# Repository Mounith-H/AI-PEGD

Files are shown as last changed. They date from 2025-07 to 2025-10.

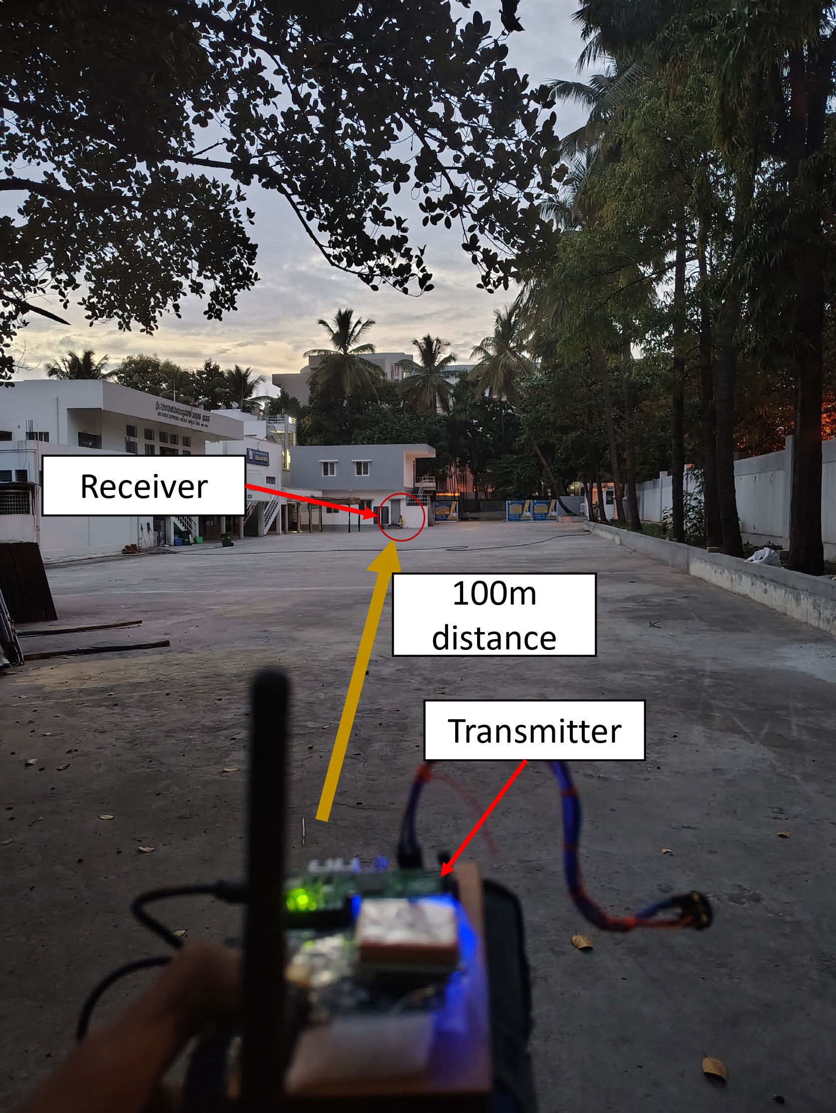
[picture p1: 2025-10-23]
images/field_test.jpg

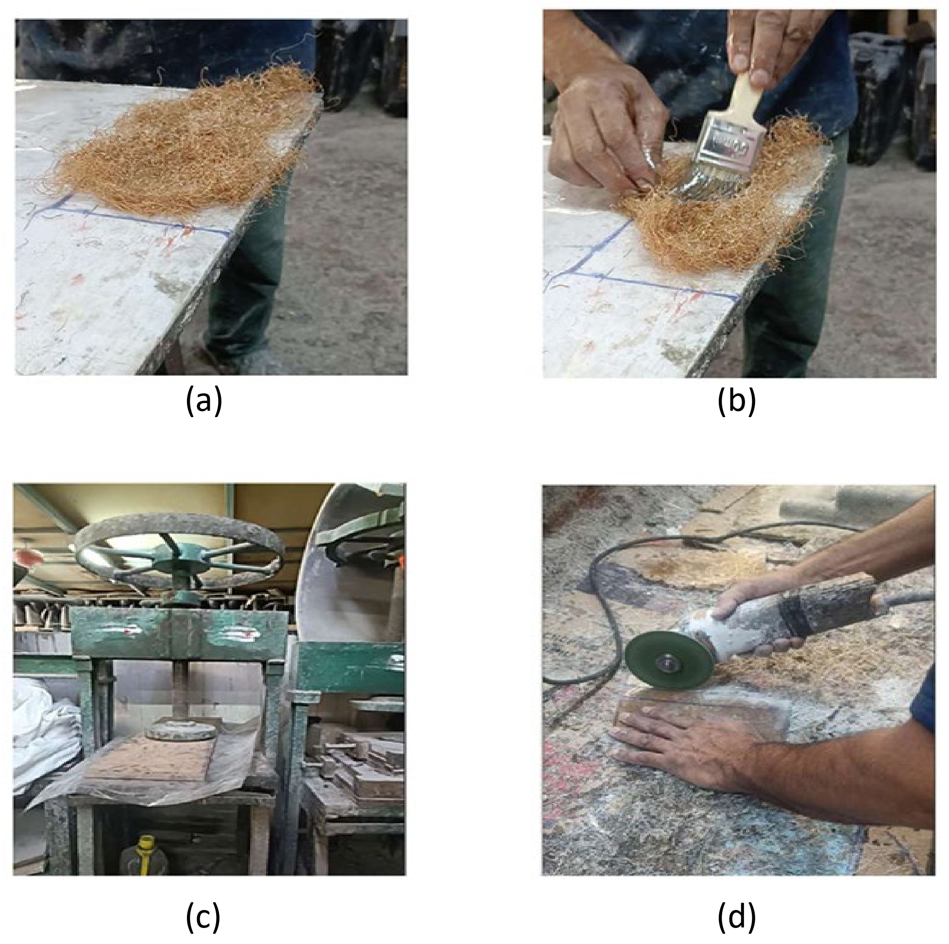
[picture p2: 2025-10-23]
images/enclosore_design.jpg

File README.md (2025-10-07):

# AI Powered Edge Based Gunshot Detection for Protecting Wildlife

## Project Overview
This project implements an intelligent gunshot detection system using Raspberry Pi Pico for wildlife protection. The system uses machine learning to detect gunshot sounds and reports their location in real-time, helping authorities respond quickly to potential poaching incidents.

## Current Implementation Status

### Completed Features
1. **Hardware Integration**
   - INMP441 Digital Microphone setup with I2S interface
   - GPS Module (NEO-6M) integration with UART
   - NRF24L01 Radio Module for wireless communication
   - Power Management using IP5306 with PIO-based PWM control:
     - Continuous KEY pin pulsing using PIO state machine
     - 16-bit resolution PWM implementation
     - Automatic power maintenance during operation

2. **Core Functionality**
   - Real-time audio sampling using PIO and DMA
   - GPS location tracking with NMEA parsing
   - Wireless data transmission with packet fragmentation
   - Power management with robust PIO implementation:
     - Efficient KEY pin control
     - Reliable power maintenance
     - Clean initialization sequence

3. **System Architecture**
   - Dual-core operation:
     - Core 0: System management, GPS, and radio communication
     - Core 1: Audio processing and gunshot detection
   - PIO-based peripheral management:
     - Audio sampling
     - Power control
     - Communication protocols

4. **Reliability Features**
   - Robust power management with PWM-based IP5306 control:
     - Continuous operation guarantee
     - Power stability monitoring
     - Automatic recovery on power events
   - Error handling and recovery mechanisms
   - Packet fragmentation for reliable data transmission
   - Automatic retry mechanisms for radio communication

### Work in Progress
1. **Machine Learning Integration**
   - TensorFlow Lite model integration
   - Model optimization for Pico
   - Real-time inference implementation

2. **Communication Protocol**
   - Mesh network implementation
   - Data encryption
   - Acknowledgment system

### Future Work
1. **System Features**
   - Web interface for monitoring
   - Mobile app development
   - Multiple node coordination
   - Over-the-air updates

2. **ML Improvements**
   - Model retraining with field data
   - False positive reduction
   - Sound classification expansion

3. **Hardware Improvements**
   - Weather-proof enclosure design
   - Solar charging integration
   - Extended range communication

## Hardware Setup
### Components
- Raspberry Pi Pico
- INMP441 Digital Microphone
- NEO-6M GPS Module
- NRF24L01 Radio Module
- IP5306 Power Management IC

- **Power Control**:
  - Power control implemented through PIO state machine
  - Continuous PWM signal maintains power module operation

## Building and Running
### Prerequisites
1. Install CMake (version 3.12 or higher)
2. Install Raspberry Pi Pico SDK
3. Set PICO_SDK_PATH environment variable

### Build Instructions
1. Create build directory:
   ```bash
   mkdir build
   cd build
   ```

2. Generate build files:
   ```bash
   cmake ..
   ```

3. Build the project:
   ```bash
   make
   ```

4. Flash the binary:
   - Hold BOOTSEL button while connecting Pico
   - Copy generated .uf2 file to mounted drive

### Power Management Notes
- The system uses PIO-based power control for the IP5306
- KEY pin requires continuous pulsing to maintain power
- PWM implementation ensures reliable operation
- No manual intervention needed after initial power-up

## Contributing
Contributions are welcome! Please read the contributing guidelines before submitting pull requests.

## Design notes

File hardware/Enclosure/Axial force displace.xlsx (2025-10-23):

MTS793|BTW|ENU|1|0|.|/|:|1|0|0|A
Data Header: Time: 2048.0078 s 5/13/2025 4:09:34 PM
Data Acquisition: Timed
Station Name: 10629574 w ext.cfg
Test File Name: Untitled test
Axial Force Axial Displacement Time
kN | mm | s
2.1577883 | 0.53644472 | 1.0058594
2.1624367 | 0.54335147 | 2.0058594
2.1644783 | 0.54634267 | 3.0058594
2.1647153 | 0.54781216 | 4.0058594
2.1628492 | 0.54907978 | 5.0058594
2.1625283 | 0.54998457 | 6.0058594
2.1607583 | 0.55126494 | 7.0058594
2.1571965 | 0.55169493 | 8.0058594
2.1579719 | 0.55303329 | 9.0058594
2.1613309 | 0.55302805 | 10.005859
2.1653202 | 0.55400676 | 11.005859
2.1636591 | 0.55546653 | 12.005859
2.1633389 | 0.55449086 | 13.005859
2.1691735 | 0.5558036 | 14.005859
2.1675892 | 0.55581975 | 15.005859
2.1672471 | 0.55782229 | 16.005859
2.1608047 | 0.55742198 | 17.005859
2.1654606 | 0.55737203 | 18.005859
2.1592593 | 0.55784929 | 19.005859
2.1604385 | 0.55761653 | 20.005859
2.1584291 | 0.55777705 | 21.005859
2.1655483 | 0.55822724 | 22.005859
2.1641695 | 0.55928248 | 23.005859
2.1653185 | 0.55874401 | 24.005859
2.16677 | 0.5593316 | 25.005859
2.167227 | 0.55964351 | 26.005859
2.1643686 | 0.56017697 | 27.005859
2.1658328 | 0.55947161 | 28.005859
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

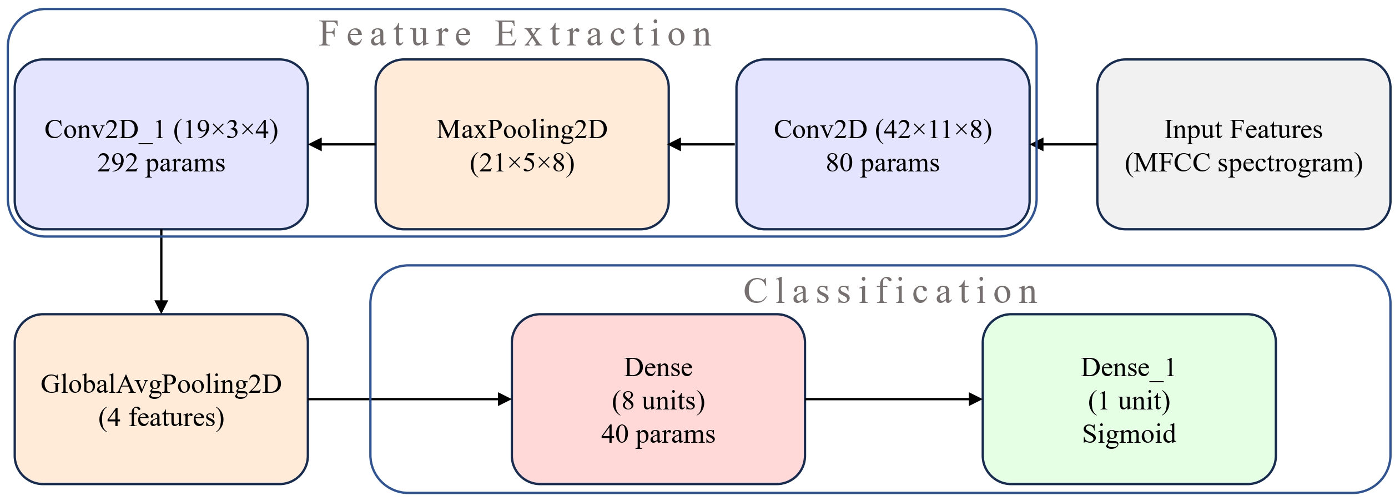
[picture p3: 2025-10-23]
images/CNN_architecture.jpg

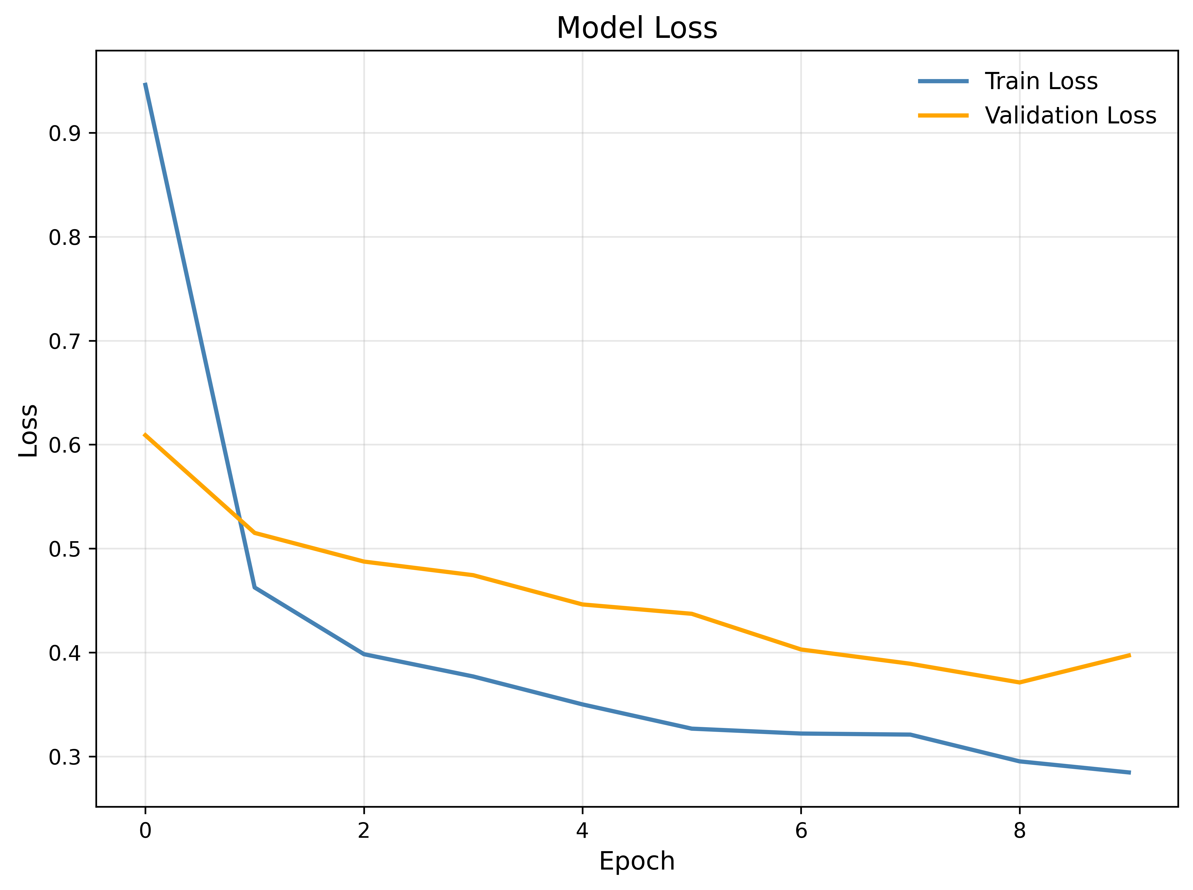
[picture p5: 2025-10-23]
images/loss_plot_400.png

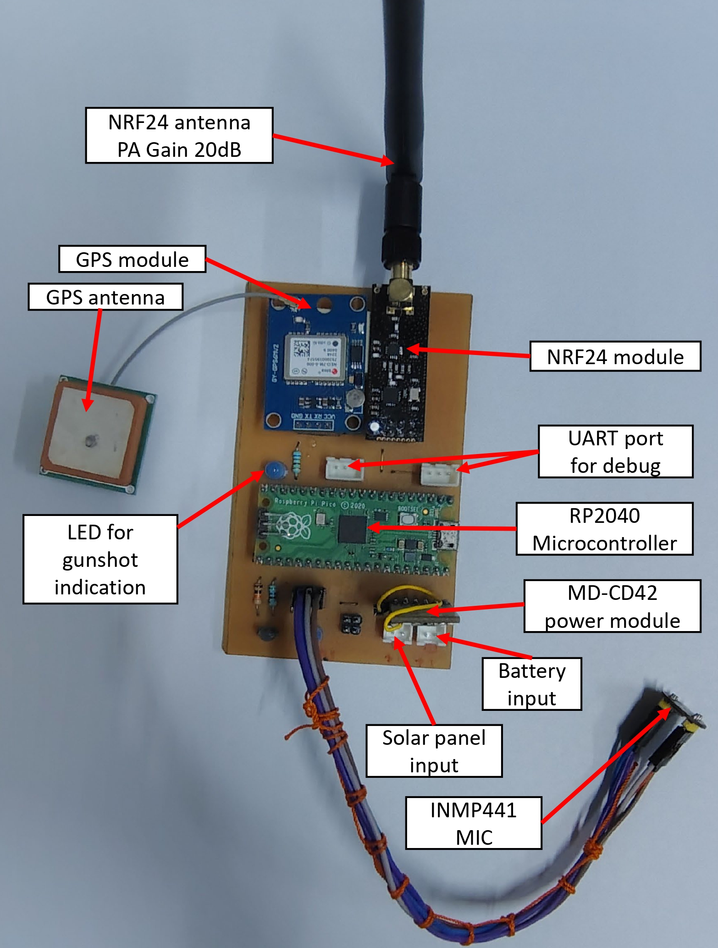
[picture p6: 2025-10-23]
images/transmitter_node.jpg

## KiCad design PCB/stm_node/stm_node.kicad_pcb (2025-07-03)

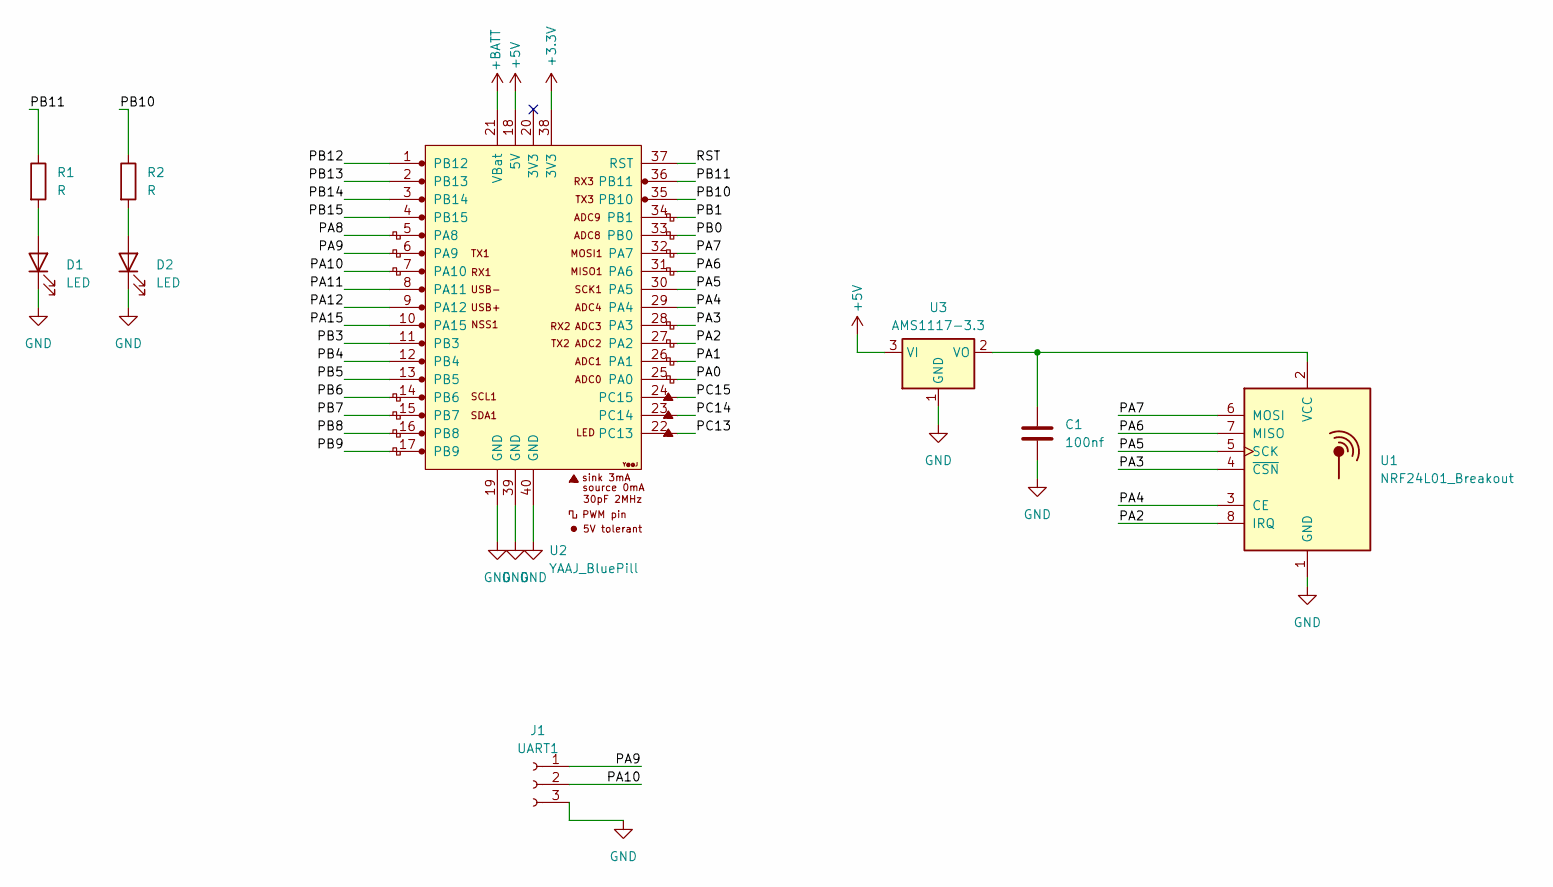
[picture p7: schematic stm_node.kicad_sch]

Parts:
C1: 100nf; CP_EIA-3528-12_Kemet-T_HandSolder
D1, D2: LED; LED_D5.0mm
J1: UART1; JST_XH_B3B-XH-A_1x03_P2.50mm_Vertical
R1, R2: R; R_Axial_DIN0207_L6.3mm_D2.5mm_P10.16mm_Horizontal
U1: NRF24L01_Breakout; nRF24L01_Breakout
U2: YAAJ_BluePill; YAAJ_BluePill_1
U3: AMS1117-3.3; SOT-223-3_TabPin2

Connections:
+3.3V: U2.38 (3V3)
+5V: U2.18 (5V), U3.3 (VI)
+BATT: U2.21 (VBat)
/PA0: U2.25 (PA0)
/PA1: U2.26 (PA1)
/PA2: U1.8 (IRQ), U2.27 (PA2)
/PA3: U1.4 (~CSN), U2.28 (PA3)
/PA4: U1.3 (CE), U2.29 (PA4)
/PA5: U1.5 (SCK), U2.30 (PA5)
/PA6: U1.7 (MISO), U2.31 (PA6)
/PA7: U1.6 (MOSI), U2.32 (PA7)
/PA8: U2.5 (PA8)
/PA9: J1.1, U2.6 (PA9)
/PA10: J1.2, U2.7 (PA10)
/PA11: U2.8 (PA11)
/PA12: U2.9 (PA12)
/PA15: U2.10 (PA15)
/PB0: U2.33 (PB0)
/PB1: U2.34 (PB1)
/PB3: U2.11 (PB3)
/PB4: U2.12 (PB4)
/PB5: U2.13 (PB5)
/PB6: U2.14 (PB6)
/PB7: U2.15 (PB7)
/PB8: U2.16 (PB8)
/PB9: U2.17 (PB9)
/PB10: R2.1, U2.35 (PB10)
/PB11: R1.1, U2.36 (PB11)
/PB12: U2.1 (PB12)
/PB13: U2.2 (PB13)
/PB14: U2.3 (PB14)
/PB15: U2.4 (PB15)
/PC13: U2.22 (PC13)
/PC14: U2.23 (PC14)
/PC15: U2.24 (PC15)
/RST: U2.37 (RST)
GND: C1.2, D1.1 (K), D2.1 (K), J1.3, U1.1 (GND), U2.19 (GND), U2.39 (GND), U2.40 (GND), U3.1 (GND)
unnamed: D1.2 (A), R1.2
unnamed: D2.2 (A), R2.2
unnamed: C1.1, U1.2 (VCC), U3.2 (VO)

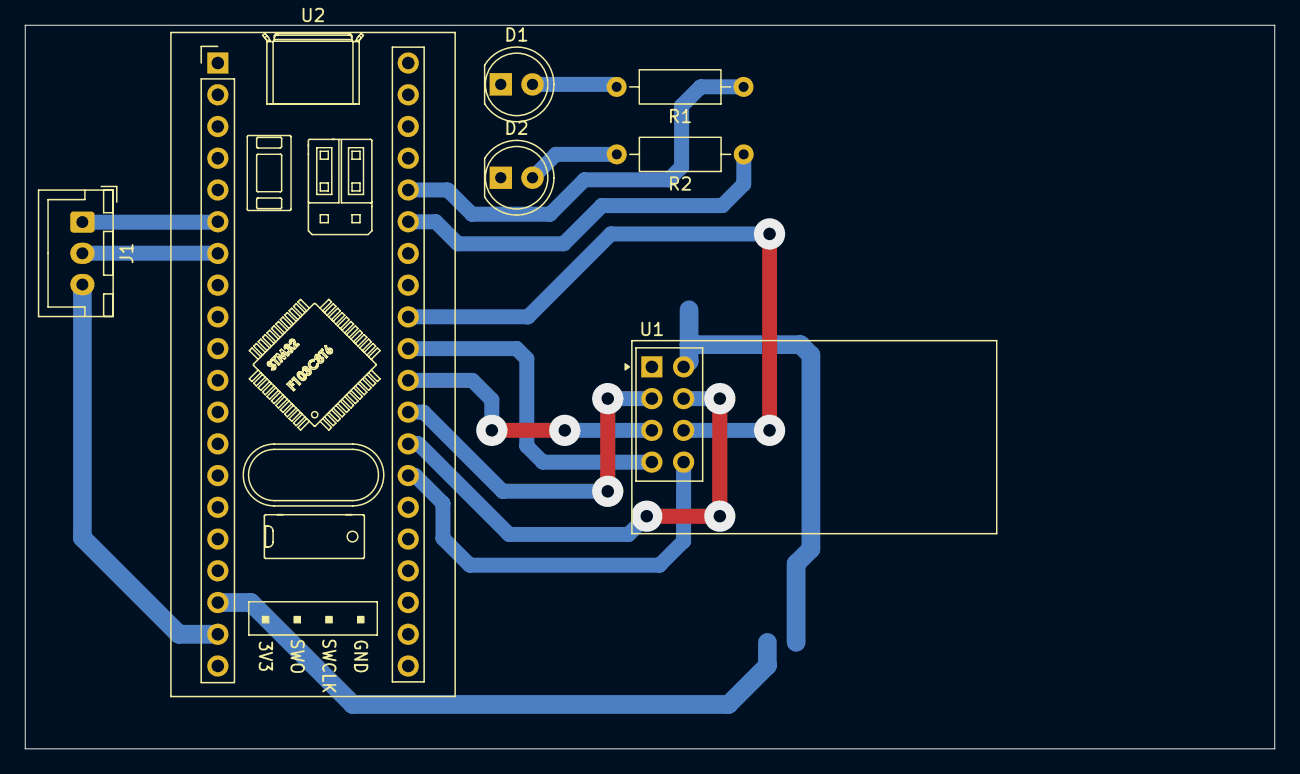
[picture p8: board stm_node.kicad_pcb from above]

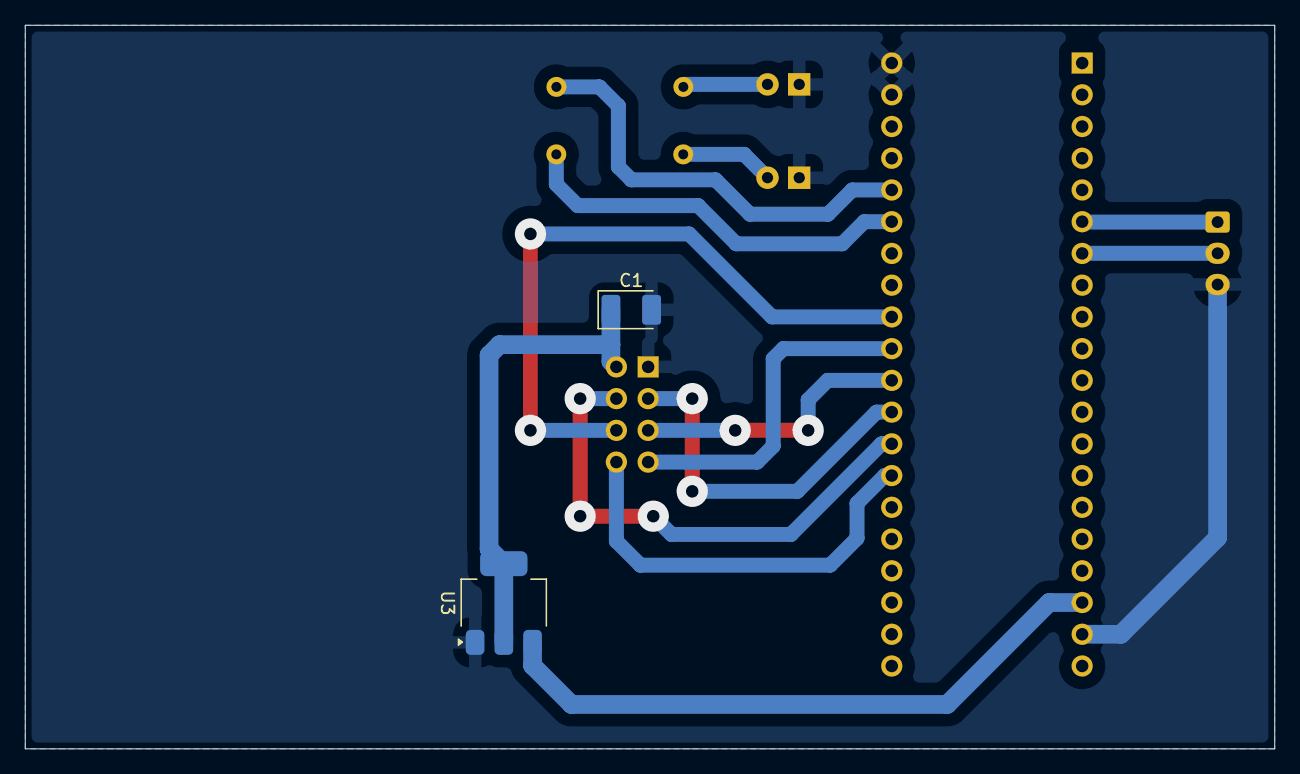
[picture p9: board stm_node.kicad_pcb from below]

Board: 2 copper layers, 100.0 x 57.9 mm, 9 parts (2 on the bottom side), 15 nets.

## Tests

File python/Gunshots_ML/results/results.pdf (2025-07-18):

# Gunshot Detection for Wildlife Protection: Machine Learning Model Results and RP2040 Deployment

### ML-Based Gunshot Detection System

### July 3, 2025

Abstract

This document presents comprehensive results from a machine learning-based gunshot detection system designed for wildlife protection. The system utilizes TensorFlow with enhanced feature extraction from audio signals and has been optimized for deployment on RP2040 microcontrollers. The model achieves 97.8% accuracy with significant size reduction through quantization for edge computing applications.

## 1 Introduction

Wildlife protection requires real-time monitoring systems capable of detecting illegal hunting activities, particularly gunshots. This project implements a machine learning solution using TensorFlow that processes audio signals to distinguish between gunshots and environmental sounds. The system has been optimized for deployment on resource-constrained RP2040 microcontrollers using TensorFlow Lite with INT8 quantization.

## 2 Dataset and Methodology

### 2.1 Dataset Composition

The training dataset consists of:

Environment Sounds: 2,000 audio samples

Gunshot Sounds: 851 audio samples

Audio Format: 2-second clips at 22.05 kHz sampling rate

Total Samples: 2,851 audio files

### 2.2 Data Balancing

To address class imbalance, the following strategy was employed:

Environment sounds: Reduced to 1,702 samples (stratified sampling)

Gunshot sounds: Oversampled to 1,702 samples

Final balanced dataset: 3,404 samples (1,702 each class)

### 2.3 Feature Extraction

The system extracts 3,045 features from each audio clip:

Table 1: Audio Feature Extraction Summary

Feature Type | Dimensions | Count
MFCC Coefficients | 20 Ö 87 frames | 1,740
Spectral Centroid | 87 frames | 87
Spectral Rolloff | 87 frames | 87
Zero Crossing Rate | 87 frames | 87
Chroma Features | 12 Ö 87 frames | 1,044
Total Features | 3,045

## 3 Model Architecture

### 3.1 Neural Network Design

The enhanced TensorFlow model consists of:

Table 2: Neural Network Architecture

Layer | Neurons Activation Dropout
Input + Dense | 256 | ReLU | 30%
BatchNorm + Dense | 128 | ReLU | 40%
BatchNorm + Dense | 64 | ReLU | 30%
BatchNorm + Dense | 32 | ReLU | 20%
Output | 1 | Sigmoid | -

### 3.2 Training Configuration

Optimizer: Adam (lr=0.001, =0.9, =0.999)

Loss Function: Binary Crossentropy

Batch Size: 16

Maximum Epochs: 100

Early Stopping: Patience = 15 epochs

Validation Split: 20%

## 4 Model Performance Results

### 4.1 Primary Metrics

The enhanced model achieved the following performance on the test set:

Table 3: Model Performance Metrics

| Metric | Score

Test Accuracy 97.80%
Test Precision | 97.94%
| Test Recall | 97.65%
| F1 Score | 97.79%

### 4.2 Confusion Matrix

The confusion matrix on the test set (681 samples):

Table 4: Confusion Matrix Results

Predicted Environment Predicted Gunshot

Actual Environment | | 334 | | 7
Actual Gunshot | 8 | 332

### 4.3 Classification Report

Detailed per-class performance:

Table 5: Per-Class Performance Metrics

Class | Precision Recall F1-Score Support
Environment | 0.98 | 0.98 | 0.98 | 341
Gunshot | 0.98 | 0.98 | 0.98 | 340
Accuracy | | | 0.98 | 681
Macro Avg | 0.98 | 0.98 | 0.98 | 681
Weighted Avg | 0.98 | 0.98 | 0.98 | 681

## 5 RP2040 Optimization Results

### 5.1 Model Quantization

For deployment on RP2040 microcontrollers, the model underwent INT8 quantization:

Table 6: Model Size Optimization

Model Format | Size | Reduction
Original (.h5) | 9.51 MB | -
TensorFlow Lite (.tflite) 0.80 MB | 91.6%
C Header (.h) | 5.0 MB | -

### 5.2 Quantized Model Performance

The quantized TensorFlow Lite model maintains high accuracy:

Table 7: Quantized Model Test Results

Metric | Value
Input Type | INT8
Output Type | INT8
Input Shape | [1, 3045]
Output Shape | [1, 1]
Test Confidence | 99.61%
Model Size | 820.02 KB

## 6 Deployment Specifications

### 6.1 RP2040 Memory Requirements

Flash Memory: 820 KB for model storage

RAM: 100 KB for tensor arena

Additional: Memory for audio buffer and feature extraction

### 6.2 Processing Pipeline

1. Audio capture (2-second clips at 22.05 kHz)
2. Feature extraction (3,045 features)
3. Feature quantization to INT8

4. Model inference using TensorFlow Lite Micro
5. Threshold-based decision (¿0.5 = Gunshot)
6. Alert generation

## 7 Test Case Results

### 7.1 Real-time Testing

Sample test results from audio files:

Table 8: Sample Test Results

File | Prediction | Confidence Alert Status
5-261433-A-15.wav Environment | 94.00% | No Alert
4 (73).wav | Gunshot | 100.00% | ALERT!

## 8 Technical Implementation

### 8.1 Key Libraries and Dependencies

TensorFlow Nightly (2.20.0.dev)

Librosa (0.9.0) for audio processing

NumPy (1.21.0) for numerical computations

Scikit-learn (1.1.0) for preprocessing and metrics

### 8.2 Quantization Strategy

Listing 1: TensorFlow Lite Quantization Configuration

# INT8 Quantization for RP2040

converter . target_spec . supported_ops = [ tf . lite . OpsSet . TFLITE_BUILTINS_INT8 ]
converter . inference_input_type = tf . int8
converter . inference_output_type = tf . int8
converter . optimizations = [ tf . lite . Optimize . DEFAULT ]

## 9 Performance Analysis

### 9.1 Strengths

High Accuracy: 97.8% classification accuracy

Balanced Performance: Similar precision and recall for both classes

Size Efficiency: 91.6% size reduction through quantization

Edge Compatibility: Optimized for RP2040 deployment

Real-time Capable: Fast inference with INT8 operations

### 9.2 Considerations

Feature extraction computational complexity

Memory constraints for audio buffering

Environmental noise adaptation requirements

Power consumption optimization for battery operation

## 10 Deployment Guidelines

### 10.1 Hardware Requirements

Microcontroller: RP2040 Pico

Audio Input: I2S microphone or ADC

Memory: 2MB Flash, 264KB RAM

Libraries: pico-tflmicro with CMSIS-NN

### 10.2 Integration Steps

1. Include generated header file (gunshot detection model.h)
2. Initialize TensorFlow Lite Micro interpreter
3. Implement audio capture and feature extraction
4. Configure tensor arena (100KB recommended)
5. Deploy inference pipeline with alert system

## 11 Conclusion

The implemented gunshot detection system demonstrates excellent performance with 97.8% accuracy and successful optimization for RP2040 deployment. The 91.6% size reduction through INT8 quantization makes it suitable for edge computing applications in wildlife protection scenarios. The system provides a robust, real-time solution for detecting illegal hunting activities with minimal computational resources.

### 11.1 Future Enhancements

Audio preprocessing optimization for real-time feature extraction

Adaptive threshold tuning based on environmental conditions

Power management strategies for extended battery life

Multi-class detection for different weapon types

Wireless communication integration for remote monitoring

## 12 Generated Files

The following files were generated for RP2040 deployment:

gunshot detection model.h5 (9.51 MB) - Original TensorFlow model

gunshot detection model.tflite (820 KB) - Quantized TensorFlow Lite model

gunshot detection model.h (5.0 MB) - C header file for compilation

gunshot detection model scaler.pkl - Feature scaler for preprocessing

RP2040 DEPLOYMENT GUIDE.md - Deployment documentation

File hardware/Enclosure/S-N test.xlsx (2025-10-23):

Test: S-N Test
Date: 5/8/2025 10:26:49 AM
Cycles to Failure (N) | Stress (MPa)
10^3.02 | 24.64
10^3.08 | 15.60
10^3.47 | 14.59
10^3.77 | 14.24
10^4.48 | 9.86

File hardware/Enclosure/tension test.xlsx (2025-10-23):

File Path: C:\Users\Administrator\Desktop\CSIS_823 05-2-25 11 36 33 AM\DAQ- Time, … - (Timed).csv
Test: Trial tension test basic 90
Test Run: CSIS_823
Date: 5/2/2025 11:31:04 AM
Time | Axial Displacement | Axial Force | Axial EXT | Stress (kN/mm^2) | Strain
sec | mm | kN | mm
35.52246094 | -0.000434458 | -0.005253707 | -0.000754926 | -5.38e-05 | -1.74e-05
35.62207031 | 0.000897057 | 0.003421097 | -0.000619296 | 3.5e-05 | 3.59e-05
35.72167969 | 0.002625168 | 0.000433647 | -0.000860851 | 4.44e-06 | 0.000105007
35.82128906 | 0.002934979 | 0.010100193 | -0.000433635 | 0.000103356 | 0.000117399
35.92089844 | 0.004052963 | 0.007865951 | -0.000675004 | 8.05e-05 | 0.000162119
36.02050781 | 0.004551249 | 0.004185247 | 0.000386909 | 4.28e-05 | 0.00018205
36.12011719 | 0.005475342 | 0.011010445 | -0.000581648 | 0.000112671 | 0.000219014
36.21972656 | 0.007407505 | 0.008731382 | 0.000286937 | 8.93e-05 | 0.0002963
36.31933594 | 0.007899745 | 0.017405603 | -0.00012045 | 0.000178113 | 0.00031599
36.41894531 | 0.008685463 | 0.012018369 | 0.000111353 | 0.000122985 | 0.000347419
36.51855469 | 0.008109452 | 0.014053192 | -0.00016186 | 0.000143808 | 0.000324378
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

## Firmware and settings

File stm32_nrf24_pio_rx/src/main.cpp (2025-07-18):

#include <Arduino.h>
#include <SPI.h>
#include "printf.h"
#include "RF24.h"

#define siran_pin PB10 // Pin for Siran mode
#define LED_PIN PB11 // Pin for LED indication

RF24 radio(PA4, PA3);  // using pin PA4 for the CE pin, and pin PA3 for the CSN pin
// IRQ pin is connected to PA2 but not used in this basic example

// Debug serial on PA9 (TX) and PA10 (RX) - Hardware Serial2
HardwareSerial DebugSerial(PA10, PA9); // RX, TX pins

// Data reconstruction variables
String completeMessage = "";
unsigned long lastPacketTime = 0;
const unsigned long PACKET_TIMEOUT = 5000; // 5 seconds timeout between packets
int fragmentCount = 0;
int expectedFragments = 0; // Will be set from header
int currentMessageId = -1;

int lastUpdateTime = 0; // Last update time for Siran mode
bool siranEnabled = false; // Siran mode enabled flag

void parseAndDisplayData(String jsonData);
void siran();

void setup() {
  Serial.begin(115200);      // USB Serial - for JSON output only
  DebugSerial.begin(115200); // Debug Serial on PA9/PA10 - for debug messages
  
  pinMode(PC13, OUTPUT); // LED pin for indication
  pinMode(siran_pin, OUTPUT); // Siran mode pin
  pinMode(LED_PIN, OUTPUT); // LED pin for indication
  digitalWrite(PC13, HIGH); // Turn off LED initially (active low)
  digitalWrite(siran_pin, LOW); // Disable Siran mode initially
  digitalWrite(LED_PIN, LOW); // Turn off LED initially

  // Initialize radio
  if (!radio.begin()) {
    DebugSerial.println("Radio hardware not responding!");
    while(1); // Hold in infinite loop
  }
  // Configuration settings.
  radio.setChannel(2);
  radio.setDataRate(RF24_2MBPS); // 2 Mbps
  radio.setPALevel(RF24_PA_LOW); // Set power level
  radio.openReadingPipe(0, (uint8_t*)"gyroc");  // using pipe 0
  radio.setCRCLength(RF24_CRC_16); // Set CRC length
  radio.setAutoAck(true); // enable AutoAck.
  radio.enableDynamicPayloads(); // Enable dynamic payloads
  // END Configuration settings.
  
  radio.startListening();  // put radio in RX mode
  delay(1000); // Allow some time for the radio to initialize
  
  DebugSerial.println("NRF24L01 Receiver Test");
  DebugSerial.println("Pin Configuration:");
  DebugSerial.println("CE  -> PA4");
  DebugSerial.println("CSN -> PA3"); 
  DebugSerial.println("SCK -> PA5");
  DebugSerial.println("MOSI-> PA7");
  DebugSerial.println("MISO-> PA6");
  DebugSerial.println("IRQ -> PA2 (not used)");
  DebugSerial.println("DEBUG TX -> PA9");
  DebugSerial.println("DEBUG RX -> PA10");
  
  // Print radio configuration details
  DebugSerial.println("\nRadio Configuration:");
  DebugSerial.print("Channel: "); DebugSerial.println(radio.getChannel());
  DebugSerial.print("Data Rate: ");
  if (radio.getDataRate() == RF24_2MBPS) DebugSerial.println("2Mbps");
  else if (radio.getDataRate() == RF24_1MBPS) DebugSerial.println("1Mbps");
  else DebugSerial.println("250kbps");
  DebugSerial.print("Power Level: ");
  if (radio.getPALevel() == RF24_PA_LOW) DebugSerial.println("Low");
  else if (radio.getPALevel() == RF24_PA_HIGH) DebugSerial.println("High");
  else if (radio.getPALevel() == RF24_PA_MAX) DebugSerial.println("Max");
  else DebugSerial.println("Min");
  DebugSerial.print("CRC Length: ");
  if (radio.getCRCLength() == RF24_CRC_16) DebugSerial.println("16-bit");
  else DebugSerial.println("8-bit");
  DebugSerial.print("Auto Ack: "); DebugSerial.println(radio.isAckPayloadAvailable() ? "Enabled" : "Disabled");
  DebugSerial.print("Dynamic Payloads: "); DebugSerial.println("Enabled");
  
  DebugSerial.println("Listening for data...");
  DebugSerial.println("Waiting for incoming transmissions...");
  DebugSerial.println("Expecting messages with 4-byte header + 20-byte data format");
  DebugSerial.println("USB Serial: JSON output only");
  DebugSerial.println("Debug Serial (PA9/PA10): Debug messages");
}  // setup

void loop() {
  static uint8_t buffer[25]; // Increased buffer size for 24 bytes + null terminator
  static char msg[150] = {0}; // Increased message buffer
  
  if (radio.available()) {
      uint8_t len = radio.getDynamicPayloadSize(); // Get payload size
      if (len >= 4 && len <= 24) { // Validate payload size (at least header, max 24 bytes)
        radio.read(buffer, len);  // Read message into buffer.
        
        // Parse header: [msg_id][fragment_num][total_fragments][data_length]
        uint8_t messageId = buffer[0];
        uint8_t fragmentNum = buffer[1];
        uint8_t totalFragments = buffer[2];
        uint8_t dataLength = buffer[3];
        
        // Extract data portion (after 4-byte header)
        char dataBuffer[21] = {0}; // Max 20 bytes data + null terminator
        if (dataLength > 0 && dataLength <= 20 && (4 + dataLength) <= len) {
          memcpy(dataBuffer, &buffer[4], dataLength);
          dataBuffer[dataLength] = '\0';
        }
        
        // Show detailed packet info on debug serial
        sprintf(msg, "Msg:%d Frag:%d/%d DataLen:%d Data:'%s'", 
                messageId, fragmentNum + 1, totalFragments, dataLength, dataBuffer);
        DebugSerial.println(msg);
        
        // Check if this is a new message
        if (currentMessageId != messageId) {
          if (completeMessage.length() > 0) {
            DebugSerial.println("New message started - clearing previous incomplete message");
          }
          completeMessage = "";
          fragmentCount = 0;
          currentMessageId = messageId;
          expectedFragments = totalFragments;
        }
        
        // Add data to complete message
        completeMessage += String(dataBuffer);
        lastPacketTime = millis();
        fragmentCount++;
        
        // Blink LED to indicate reception
        digitalWrite(LED_PIN, HIGH);  // Turn on LED
        delay(10);
        digitalWrite(LED_PIN, LOW); // Turn off LED
        
        // Check if we've received all expected fragments
        if (fragmentCount >= expectedFragments) {
          DebugSerial.println("\n=== COMPLETE MESSAGE RECEIVED ===");
          DebugSerial.println("Message ID: " + String(messageId));
          DebugSerial.println("Total fragments: " + String(fragmentCount));
          DebugSerial.println("Complete message: " + completeMessage);
          
          // Try to parse as JSON
          if (completeMessage.indexOf('{') != -1 && completeMessage.indexOf('}') != -1) {
            int startPos = completeMessage.indexOf('{');
            int endPos = completeMessage.lastIndexOf('}') + 1;
            
            if (startPos != -1 && endPos > startPos) {
              String jsonMessage = completeMessage.substring(startPos, endPos);
              
              // Send JSON to USB Serial ONLY
              Serial.println(jsonMessage);
              
              // Send parsed data to debug serial
              parseAndDisplayData(jsonMessage);
            }
          } else {
            DebugSerial.println("Message doesn't appear to be JSON format");
          }
          
          DebugSerial.println("=================================\n");
          
          // Clear the buffer for next message
          completeMessage = "";
          fragmentCount = 0;
          currentMessageId = -1;
          expectedFragments = 0;
        }
      }
  }
  
  // Check for timeout - clear incomplete message if too much time has passed
  if (completeMessage.length() > 0 && (millis() - lastPacketTime) > PACKET_TIMEOUT) {
    DebugSerial.println("Message timeout - clearing incomplete data");
    DebugSerial.println("Message ID: " + String(currentMessageId));
    DebugSerial.println("Fragments received before timeout: " + String(fragmentCount) + "/" + String(expectedFragments));
    DebugSerial.println("Partial message: " + completeMessage);
    completeMessage = "";
    fragmentCount = 0;
    currentMessageId = -1;
    expectedFragments = 0;
  }

  siran();
  if(Serial.available()){
    char c = Serial.read();
    if(c == '0'){
      siranEnabled = false;
      DebugSerial.println("Siran disabled");
    }
    else DebugSerial.println("Invalid command received: " + String(c));
  }
  // Add a small delay to prevent overwhelming the serial output
  delay(10);
}

void siran() {
  if (siranEnabled) {

    // turn on siran_pin for 2 seconds and off for 1 second and repeat in non blocking way
    if(millis() - lastUpdateTime > 3000) {
      digitalWrite(siran_pin, HIGH); // Turn on Siran mode
      digitalWrite(LED_PIN, HIGH); // Turn on LED indication
      DebugSerial.println("Siran mode enabled");
      lastUpdateTime = millis();
    } else if (millis() - lastUpdateTime > 2000) {
      digitalWrite(siran_pin, LOW); // Turn off Siran mode
      digitalWrite(LED_PIN, LOW); // Turn off LED indication
    }
    
  } else {
      digitalWrite(siran_pin, LOW); // Turn off Siran mode
      digitalWrite(LED_PIN, LOW); // Turn off LED indication
  }
  // This function can be expanded based on the requirements of the Siran mode
}

void parseAndDisplayData(String jsonData) {
  DebugSerial.println("=== PARSED DATA ===");
  
  // Extract Node ID
  int nodeIdStart = jsonData.indexOf("\"node_id\":\"") + 11;
  int nodeIdEnd = jsonData.indexOf("\"", nodeIdStart);
  if (nodeIdStart > 10 && nodeIdEnd > nodeIdStart) {
    String nodeId = jsonData.substring(nodeIdStart, nodeIdEnd);
    DebugSerial.println("Node ID: " + nodeId);
  }
  
  // Extract Message ID
  int msgIdStart = jsonData.indexOf("\"msg\":\"") + 7;
  int msgIdEnd = jsonData.indexOf("\"", msgIdStart);
  if (msgIdStart > 6 && msgIdEnd > msgIdStart) {
    String msgId = jsonData.substring(msgIdStart, msgIdEnd);
    DebugSerial.println("Message ID: " + msgId);
  }
  
  // Extract ID (if present)
  int idStart = jsonData.indexOf("\"_id\":\"") + 7;
  int idEnd = jsonData.indexOf("\"", idStart);
  if (idStart > 6 && idEnd > idStart) {
    String id = jsonData.substring(idStart, idEnd);
    DebugSerial.println("ID: " + id);
  }
  
  // Extract Date
  int dateStart = jsonData.indexOf("\"date\":\"") + 8;
  int dateEnd = jsonData.indexOf("\"", dateStart);
  if (dateStart > 7 && dateEnd > dateStart) {
    String date = jsonData.substring(dateStart, dateEnd);
    DebugSerial.println("Date: " + date);
  }
  
  // Extract Time
  int timeStart = jsonData.indexOf("\"time\":\"") + 8;
  int timeEnd = jsonData.indexOf("\"", timeStart);
  if (timeStart > 7 && timeEnd > timeStart) {
    String time = jsonData.substring(timeStart, timeEnd);
    DebugSerial.println("Time: " + time);
  }
  
  // Extract Latitude
  int latStart = jsonData.indexOf("\"latitude\":\"") + 12;
  int latEnd = jsonData.indexOf("\"", latStart);
  if (latStart > 11 && latEnd > latStart) {
    String latitude = jsonData.substring(latStart, latEnd);
    DebugSerial.println("Latitude: " + latitude);
  }
  
  // Extract Longitude
  int lonStart = jsonData.indexOf("\"longitude\":\"") + 13;
  int lonEnd = jsonData.indexOf("\"", lonStart);
  if (lonStart > 12 && lonEnd > lonStart) {
    String longitude = jsonData.substring(lonStart, lonEnd);
    DebugSerial.println("Longitude: " + longitude);
  }
  
  // Extract Confidence
  int confStart = jsonData.indexOf("\"confidence\":") + 13;
  int confEnd = jsonData.indexOf("}", confStart);
  if (confStart > 12 && confEnd > confStart) {
    String confidence = jsonData.substring(confStart, confEnd);
    DebugSerial.println("Confidence: " + confidence);
  }
  siranEnabled = true;
  DebugSerial.println("Siran enabled");
  DebugSerial.println("==================");
}

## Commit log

2025-07-03 ML Model added and implemented on pico
    [stm_node.kicad_pcb, stm_node.kicad_sch]
2025-07-18 updated ML model using Edge impulse updated INMP441 pio code
    [pico_node.kicad_sch, stm_node.kicad_sch]
2025-10-23 add ML figures, metrics, models and hardware logs
    [Axial force displace.xlsx, S-N test.xlsx, accuracy_plot_data__1000.csv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]
